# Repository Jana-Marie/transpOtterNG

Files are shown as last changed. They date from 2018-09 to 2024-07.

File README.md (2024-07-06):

# TranspOtterNG

Next Generation of TranspOtter.

[Firmware](https://github.com/NiklasFauth/hoverboard-firmware-hack/tree/transpotter)

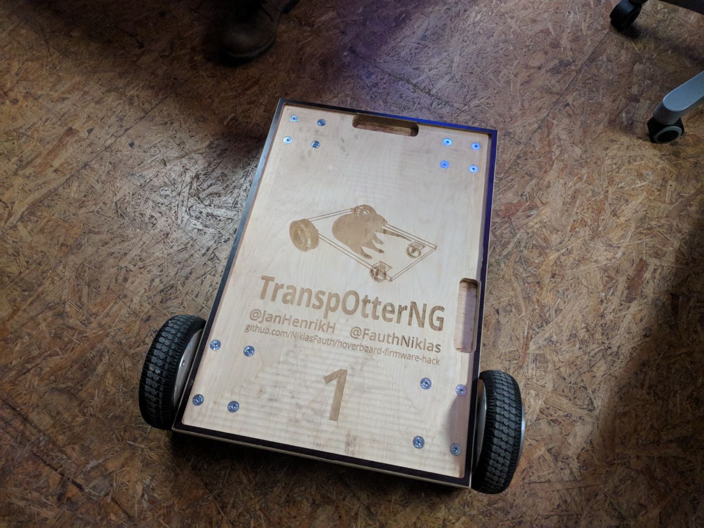
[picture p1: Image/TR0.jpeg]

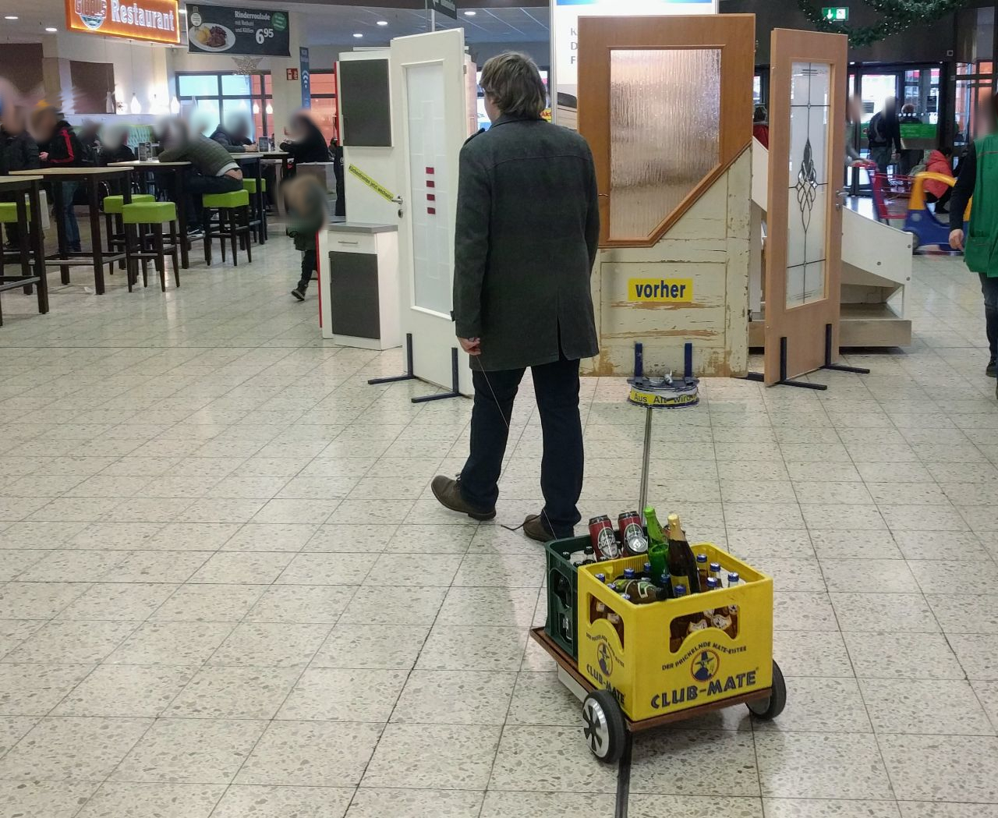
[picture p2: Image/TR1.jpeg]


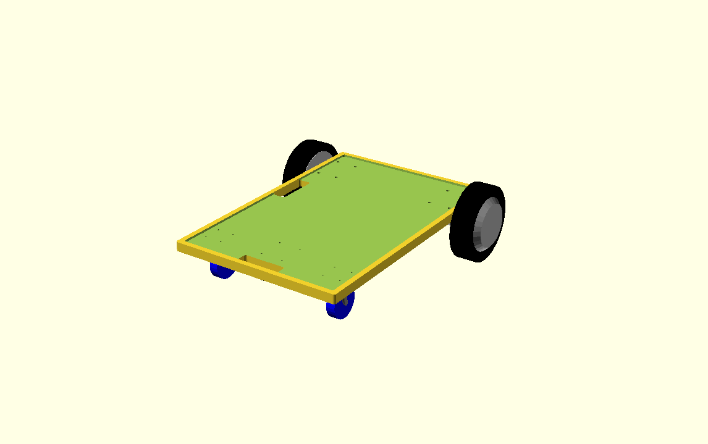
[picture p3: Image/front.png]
Front

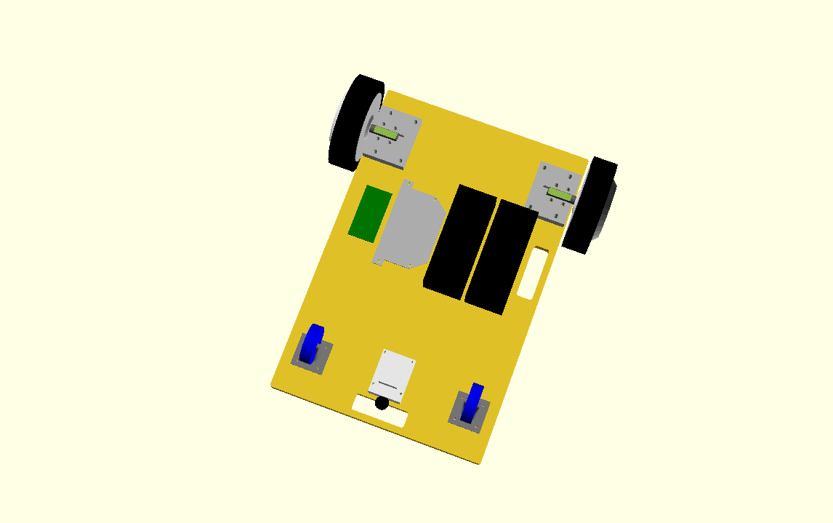
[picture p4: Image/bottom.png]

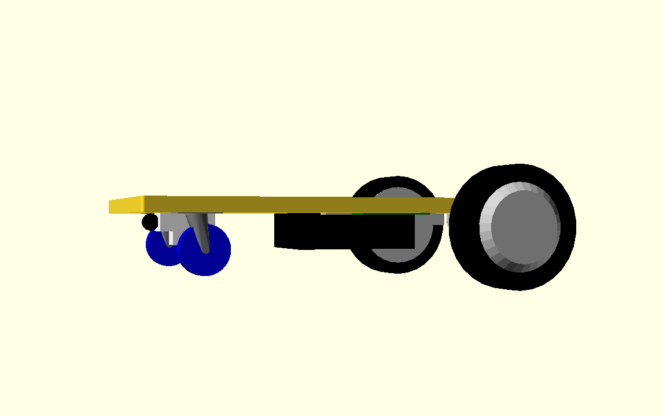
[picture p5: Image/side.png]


[Generation 1](https://github.com/NiklasFauth/hoverboard-firmware-hack/wiki/Build-Instruction:-TranspOtter)

## Libs

https://github.com/Jana-Marie/KiCAD-libs

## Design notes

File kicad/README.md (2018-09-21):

# Kicad project

This PCB will connect the mainboard to the Nunchuck, Gametrak and the Display.
Also it will provide 5V and 3.3V as well as the emergency stop.

## To do:

 - Add ESP and RFM69
 - Fit connectors
 - Check size
 - Add an Otter

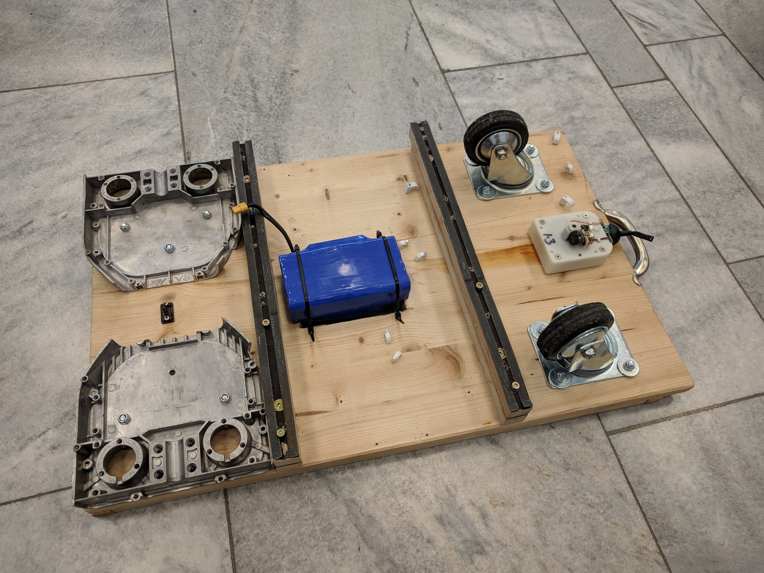
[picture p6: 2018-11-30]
Image/docs/board_bare_overview.jpg

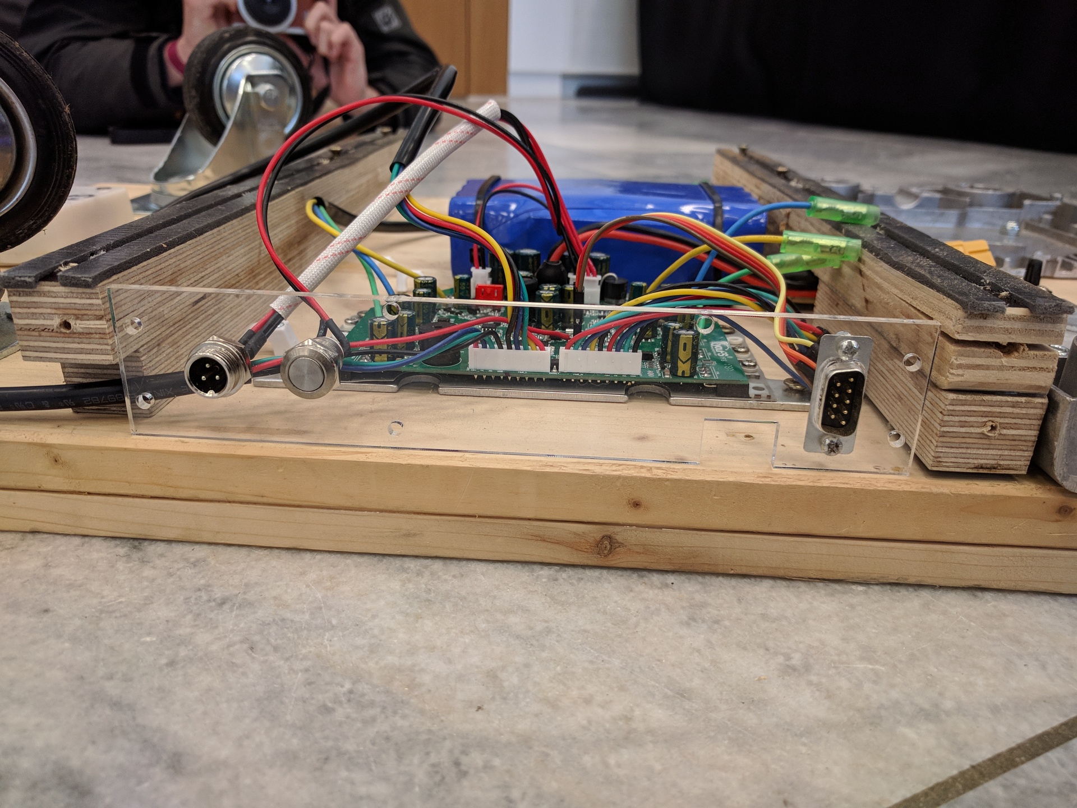
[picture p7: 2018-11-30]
Image/docs/panel_overview.jpg

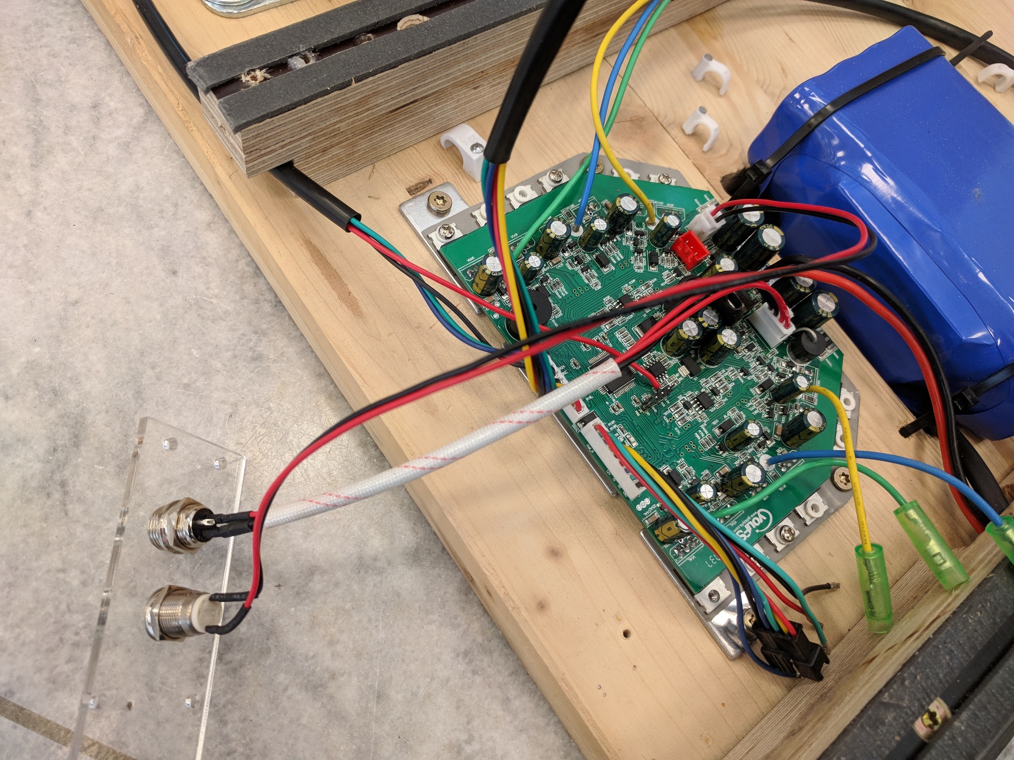
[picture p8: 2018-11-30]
Image/docs/charger_and_button.jpg

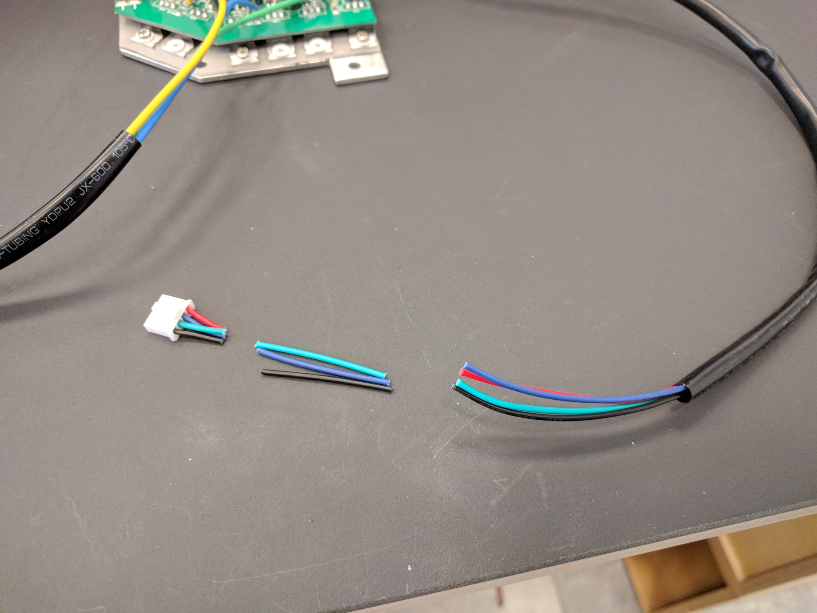
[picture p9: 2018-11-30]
Image/docs/remove_connector.jpg

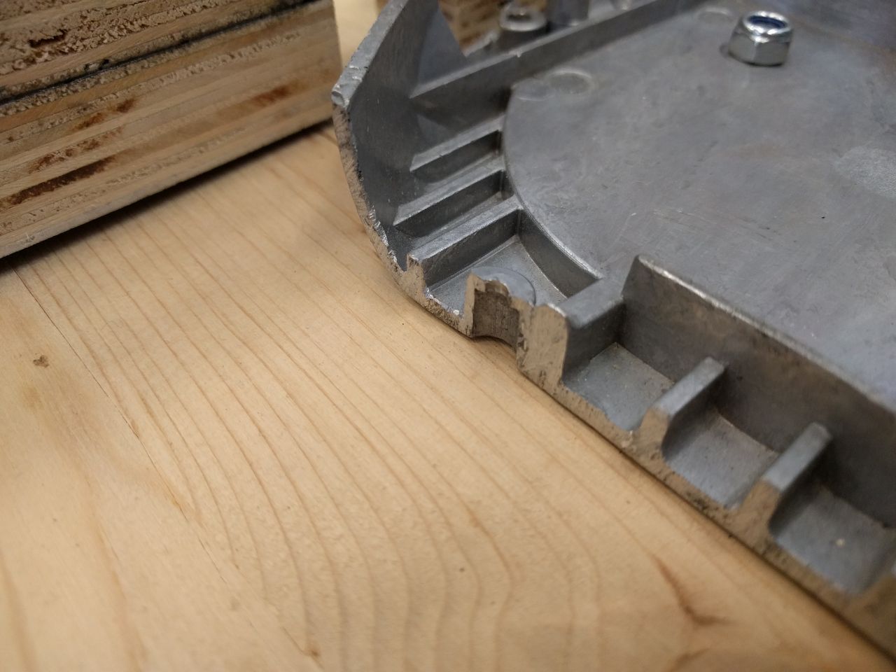
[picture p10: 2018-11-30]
Image/docs/motor_bracket_deburr.jpg

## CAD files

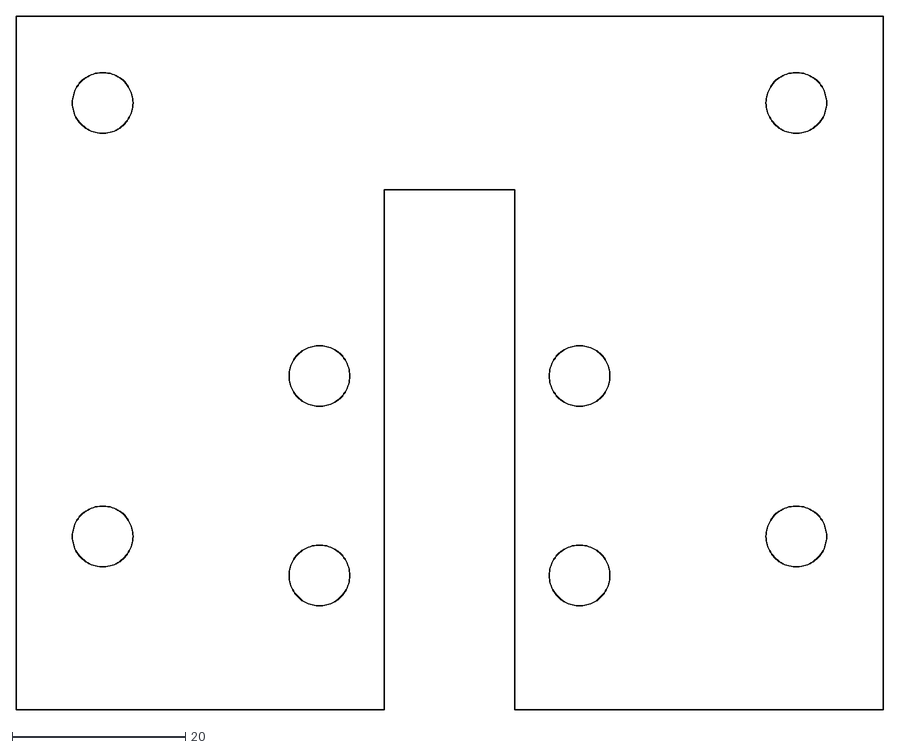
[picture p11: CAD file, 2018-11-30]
CAD/TranspOtterNG_Motor.dxf
100.0 x 80.0

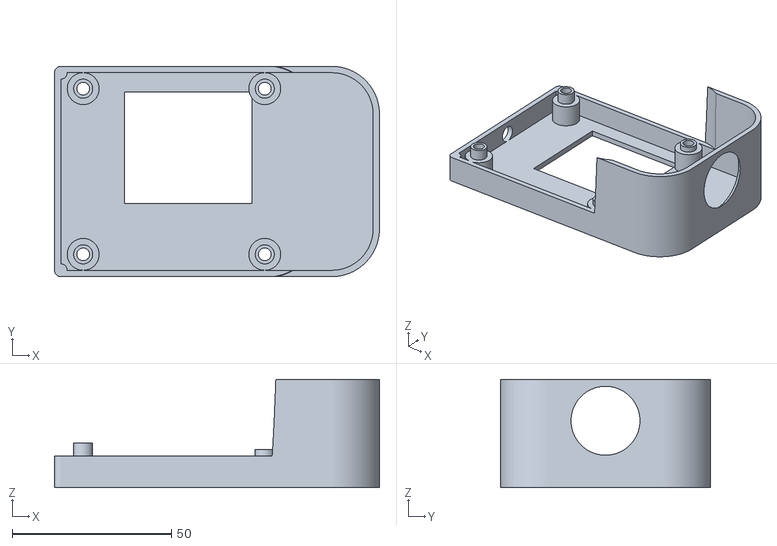
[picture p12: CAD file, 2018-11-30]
CAD/gametrak_base.stl
102.0 x 66.0 x 34.0

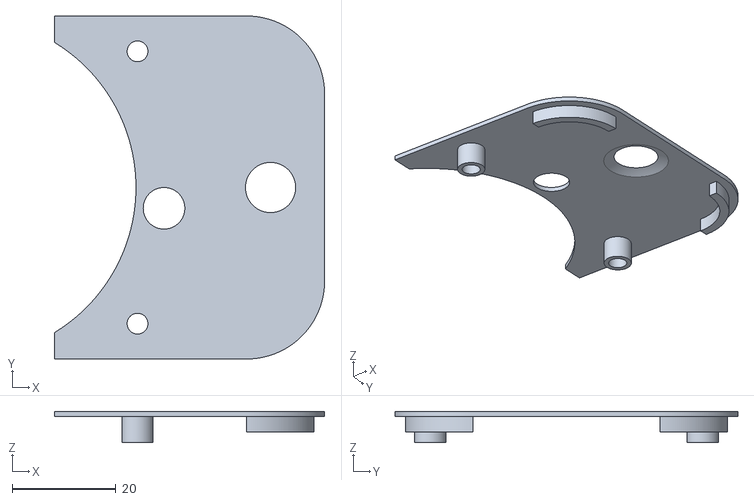
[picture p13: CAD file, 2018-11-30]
CAD/gametrak_top.stl
52.0 x 66.0 x 6.00

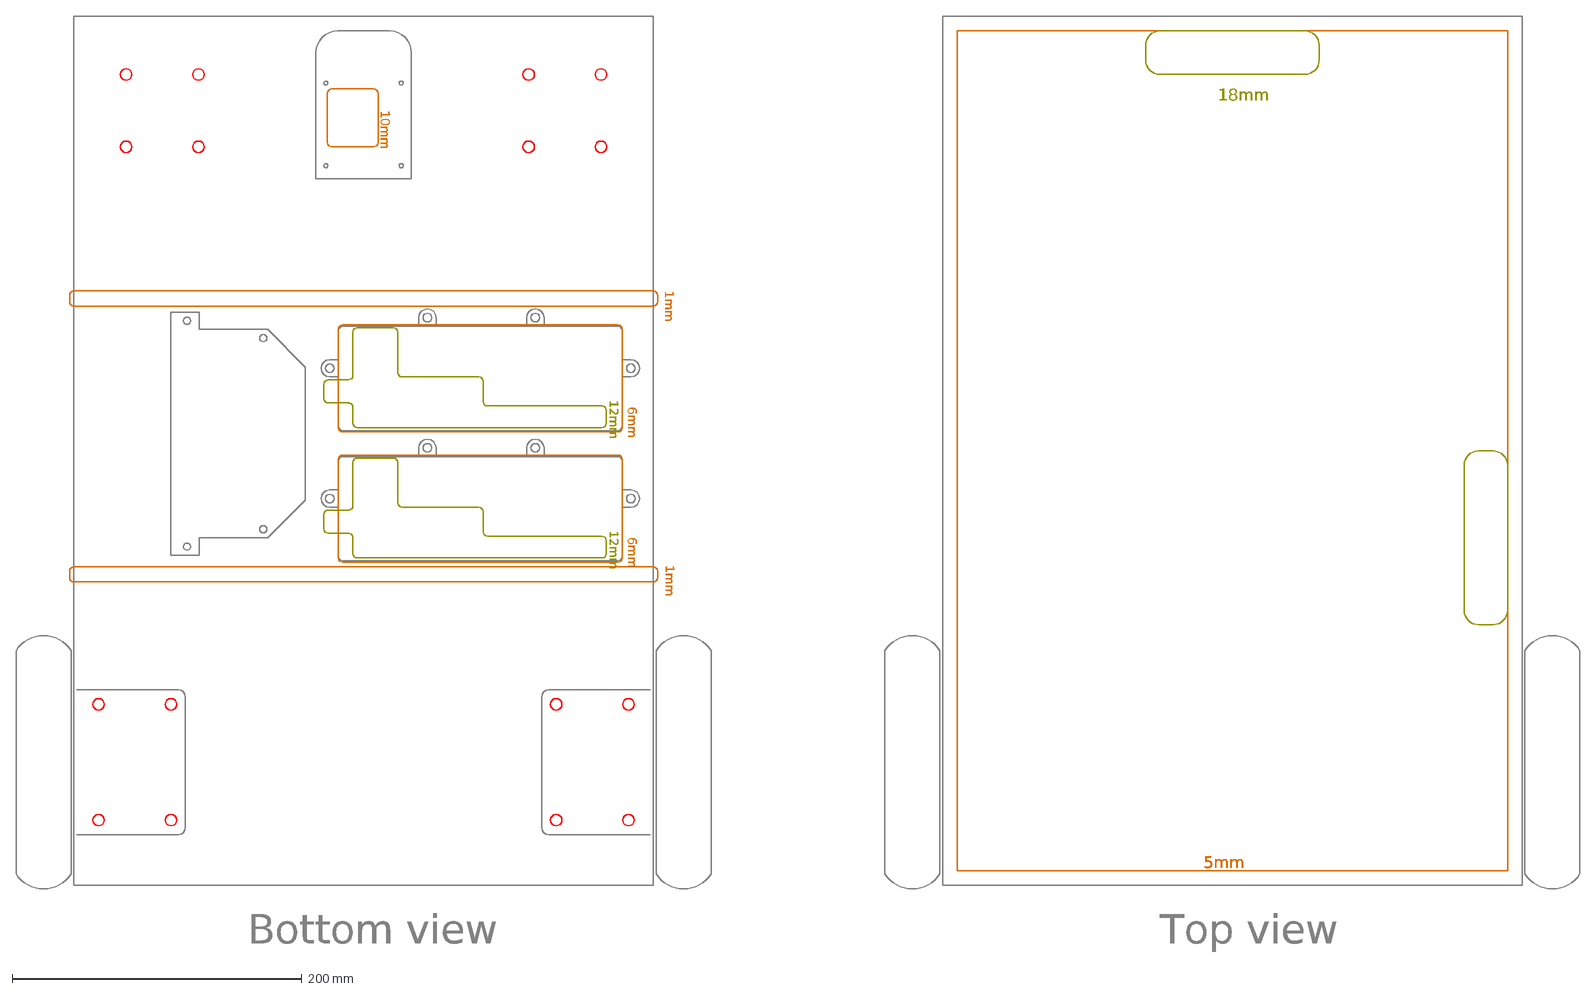
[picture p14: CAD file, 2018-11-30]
CAD/design.dxf
6mm
12mm
10mm
1mm
Bottom view
Top view
18mm
5mm

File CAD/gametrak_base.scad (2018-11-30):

$fn = 200;

difference() {
    translate([0,-31,0])cube([102-15,62,2]);
    translate([22,-10,-0.5])cube([40,35,3]);
    translate([9,-26,0])cylinder(r = 2, h = 20);
    translate([9,26,0])cylinder(r = 2, h = 20);
    translate([66,-26])cylinder(r = 2, h = 20);
    translate([66,26,0])cylinder(r = 2, h = 20);
}

translate([87,18,0])cylinder(r = 15, h = 2);
translate([87,-18,0])cylinder(r = 15, h = 2);
translate([87,-18,0])cube([15,35,2]);
    

translate([2,-31,0])cylinder(r = 2, h = 10);
translate([2,31,0])cylinder(r = 2, h = 10);

difference() {
    translate([0,-31,0])cube([2,62,10]);
    translate([0,0,5])rotate([0,90,0])cylinder(d=6, h = 5);
}

translate([2,-33,0])cube([85,2,10]);
translate([2,31,0])cube([85,2,10]);

difference() {
    union() {
        translate([9,-26,0])cylinder(r = 5, h = 10);
        translate([9,26,0])cylinder(r = 5, h = 10);
        translate([66,-26])cylinder(r = 5, h = 10);
        translate([66,26,0])cylinder(r = 5, h = 10);
        
        translate([9,-26,0])cylinder(r = 3, h = 14);
        translate([9,26,0])cylinder(r = 3, h = 14);
        translate([66,-26])cylinder(r = 3, h = 12);
        translate([66,26,0])cylinder(r = 3, h = 12);
    }
    translate([9,-26,0])cylinder(r = 2, h = 20);
    translate([9,26,0])cylinder(r = 2, h = 20);
    translate([66,-26])cylinder(r = 2, h = 20);
    translate([66,26,0])cylinder(r = 2, h = 20);
}

/*
intersection() {
    difference() {
        translate([67,18,0])cylinder(r = 15, h = 10);
        translate([67,18,0])cylinder(r = 13, h = 10);
    }
    translate([67,18,0])cube([15,15,10]);
}

intersection() {
    difference() {
        translate([67,-18,0])cylinder(r = 15, h = 10);
        translate([67,-18,0])cylinder(r = 13, h = 10);
    }
    translate([67,-18-15,0])cube([15,15,10]);
}
*/

intersection() {
    difference() {
        translate([87,18,0])cylinder(r = 15, h = 34);
        translate([87,18,0])cylinder(r = 13, h = 34);
    }
    translate([87,18,0])cube([15,15,34]);
}

intersection() {
    difference() {
        translate([87,-18,0])cylinder(r = 15, h = 34);
        translate([87,-18,0])cylinder(r = 13, h = 34);
    }
    translate([87,-18-15,0])cube([15,15,34]);
}

difference() {
    translate([67,31,0])cube([20,2,34]);
    translate([67,18,0])cylinder(r1 = 15, r2 = 15.2, h = 34);
}

difference() {
    translate([67,-33,0])cube([20,2,34]);
    translate([67,-18,0])cylinder(r1 = 15, r2 = 15.2, h = 34);
}

difference() {
    translate([100,-18,0])cube([2,36,34]);
    translate([91.6,0,21])rotate([0,90,0])sphere(d=30);
    //translate([99,0,21])rotate([0,90,0])resize([15,20])cylinder(d=20, h=5);
}

/*
difference() {
    union() {
        translate([87,18,33])cylinder(r = 15, h = 1);
        translate([87,-18,33])cylinder(r = 15, h = 1);
        translate([87,-18,33])cube([15,35,1]);
        translate([87-20,-18-15,33])cube([20,66,1]);
    }
translate([67,-18,31])cylinder(r1 = 15, r2 = 15.2, h = 10);
translate([67,18,31])cylinder(r1 = 15, r2 = 15.2, h = 12);
translate([67,-18,31])cube([15,35,3]);
}*/
//translate([81,-17.5,33])cube([15,35,1]);

    
    
    
    
    
    
    
    
    
    
    
    
    
    
    
    
    
    
    

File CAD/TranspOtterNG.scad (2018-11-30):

$fn=9;
//    batteryBosch3D();

motorplate2D_part2();

module frame2D(){
    height = 21;
    cutout_depht = 5;
    
    hoverbaord_motor_offset = -210;
    hoverbaord_motor_mount_spacing = -157;
    hoverbaord_motor_spacing = -147;
    
    wheel_offset = 220;
    wheel_spacing = 150;
    
    gametrak_offset = 210;
    
    mainboard_offset = -60;
    mainboard_offset_y = 110;
    mainboard_rotation = 270;
    
    pcb_offset = -60;
    pcb_offset_y = 10; 
    
    battery_offset_x = -60;
    battery_offset_y = -70;
    battery_rotation = 0;
    
    
    difference(){
        union(){
                base2D();

            
        }union(){
            translate([0,0,height-(cutout_depht/2)])
                cutout2D();
            
            
            translate([hoverbaord_motor_offset,hoverbaord_motor_mount_spacing,0])
                motorplate2D_cutout();
            
            
            mirror([0,1,0])
            translate([hoverbaord_motor_offset,hoverbaord_motor_mount_spacing,0])
                motorplate2D_cutout();
            
            
            translate([wheel_offset,wheel_spacing,0])
                wheel2D_cutout();
            
                        
            mirror([0,1,0])
            translate([wheel_offset,wheel_spacing,0])           
                wheel2D_cutout();
            
            
            translate([gametrak_offset,0,10])
                gametrak2D();
            
        }
    }
}

module frame3D(){
    height = 21;
    cutout_depht = 5;
    
    hoverbaord_motor_offset = -210;
    hoverbaord_motor_mount_spacing = -157;
    hoverbaord_motor_spacing = -147;
    
    wheel_offset = 220;
    wheel_spacing = 150;
    
    gametrak_offset = 210;
    
    mainboard_offset = -60;
    mainboard_offset_y = 120;
    mainboard_rotation = 270;
    
    pcb_offset = -60;
    pcb_offset_y = 10; 
    
    battery_offset_x = -50;
    battery_offset_y = -70;
    battery_rotation = 0;
    
    difference(){
        union(){
            translate([0,0,height/2])
            linear_extrude(height = height, center = true, convexity = 10,  slices = 20) {
                base2D();
            }
            
            translate([hoverbaord_motor_offset,hoverbaord_motor_mount_spacing,0])
            color("silver")
            motorplate3D();
                        
            mirror([0,1,0])
            translate([hoverbaord_motor_offset,hoverbaord_motor_mount_spacing,0])
            color("silver")
            motorplate3D();
            
            translate([hoverbaord_motor_offset,hoverbaord_motor_spacing,-20])
            motor3D();
                        
            mirror([0,1,0])
            translate([hoverbaord_motor_offset,hoverbaord_motor_spacing,-20])
            motor3D();
            
            translate([wheel_offset,wheel_spacing,0])
            wheel3D();
                        
            mirror([0,1,0])
            translate([wheel_offset,wheel_spacing,0])
            wheel3D();
            
            translate([gametrak_offset,0,0])
            gametrak3D();
            
            translate([mainboard_offset,mainboard_offset_y,-1])
            rotate([0,0,mainboard_rotation])
            mainboard3D();
            
            translate([pcb_offset,mainboard_offset_y+pcb_offset_y,-1])
            rotate([0,0,mainboard_rotation])
            pcb3D();

            
        }union(){
            translate([0,0,height-(cutout_depht/2)])
            linear_extrude(height = cutout_depht+0.01, center = true, convexity = 10,  slices = 20) {
                cutout2D();
            }
            
            translate([hoverbaord_motor_offset,hoverbaord_motor_mount_spacing,height/2])
            linear_extrude(height = height+0.01, center = true, convexity = 10,  slices = 20) {
                motorplate2D_cutout();
            }
            
            mirror([0,1,0])
            translate([hoverbaord_motor_offset,hoverbaord_motor_mount_spacing,height/2])
            linear_extrude(height = height+0.01, center = true, convexity = 10,  slices = 20) {
                motorplate2D_cutout();
            }
            
            translate([wheel_offset,wheel_spacing,10])
            linear_extrude(height = height+0.01, center = true, convexity = 10,  slices = 20) {
                wheel2D_cutout();
            }
                        
            mirror([0,1,0])
            translate([wheel_offset,wheel_spacing,10])           
            linear_extrude(height = height+0.01, center = true, convexity = 10,  slices = 20) {
                wheel2D_cutout();
            }
            
            translate([gametrak_offset,0,10])
            linear_extrude(height = height+0.01, center = true, convexity = 10,  slices = 20) {
                gametrak2D();
            }
        }
    }
    translate([battery_offset_x,battery_offset_y+(72/2)+5.5,-56/2])
    rotate([0,0,battery_rotation])
    batteryBosch3D();
    
    translate([battery_offset_x,battery_offset_y-(72/2)-5.5,-56/2])
    rotate([0,0,battery_rotation])
    batteryBosch3D();
}
module base2D(){
    length = 600;
    width = 400;
    rad = 5;
    //handle
    handle_length = 100;
    handle_width = 30;
    handle_offset = 24.5;
    handle_rad = 5;
    difference(){
        union(){
            minkowski(){
                square([length-(rad*2),width-(rad*2)],center=true);
                circle(r=rad);
            }
        }union(){
            //Handle 1
            translate([(length-handle_width-handle_offset)/2,0])
            minkowski(){
                square([handle_width-(handle_rad*2),handle_length-(handle_rad*2)],center=true);
                circle(r=handle_rad);
            }
            //Handle 2
            translate([-60,(-width+handle_width+handle_offset)/2])
            minkowski(){
                square([handle_length-(handle_rad*2),handle_width-(handle_rad*2)],center=true);
                circle(r=handle_rad);
            }
        }
    }
}

module cutout2D(){
    length = 575;
    width = 375;
    rad = 5;
    difference(){
        union(){
            minkowski(){
                square([length-(rad*2),width-(rad*2)],center=true);
                circle(r=rad);
            }
        }union(){
        }
    }
}

module gametrak2D(){
    mount_hole_size = 4.1;
    mount_hole_x = 60;
    mount_hole_y = 52;
    mount_hole_offset = -5;
    
    for(i = [-1:2:1]){
        for(j=[-1:2:1]){
            translate([i*(mount_hole_x/2)+mount_hole_offset,j*(mount_hole_y/2)])
            circle(d=mount_hole_size);
        }
    }
}

module gametrak3D(){
    translate([0,0,-(27/2)])
    difference(){
        union(){
            color("white")
            cube([80,60,27],center=true);
            translate([0,0,-(27/2)-(20/2)])
            color("white")
            cube([40,35,20],center=true);
            color("black")
            translate([50,0,0])
            sphere(d=25);
            
        }union(){
            linear_extrude(height = 27, center = true, convexity = 10,  slices = 20) {
                gametrak2D();
            }
        }
    }
}

module motorplate3D(){
    height = 10;
    height2 = 10;
    translate([0,0,-height/2])
    linear_extrude(height = height, center = true, convexity = 10,  slices = 20) {
        motorplate2D();
    }
    translate([0,0,-height-height2/2])
    linear_extrude(height = height2, center = true, convexity = 10,  slices = 20) {
        motorplate2D_part2();
    }
}

module motorplate2D_cutout(){
    mount_hole_size = 7;
    mount_hole_x = 80;
    mount_hole_y = 50;
    mount_hole_offset = 5;
    
    for(i = [-1:2:1]){
        for(j=[-1:2:1]){
            translate([i*(mount_hole_x/2),j*(mount_hole_y/2)+mount_hole_offset])circle(d=mount_hole_size);
        }
    }
}

module motorplate2D(){
    length = 80;
    width = 100;
    board_hole_size = 7;
    board_hole_x = 30;
    board_hole_y = 23;
    board_hole_offset = -13;
    difference(){
        union(){
            square([width,length],center=true);
        }union(){
           motorplate2D_cutout();
            for(i = [-1:2:1]){
                for(j=[-1:2:1]){
                    translate([i*(board_hole_x/2),j*(board_hole_y/2)+board_hole_offset])
                    circle(d=board_hole_size);
                }
            }
        }
    }
}

module motorplate2D_part2(){
    length = 80;
    width = 100;
    shaft_width = 15;
    shaft_length = 60;
    
    difference(){
        union(){
            motorplate2D();
        }union(){
            motorplate2D_cutout();
            translate([0,-(length/2)+(shaft_length/2)])
            square([shaft_width,shaft_length],center=true);
        }
    }
}
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

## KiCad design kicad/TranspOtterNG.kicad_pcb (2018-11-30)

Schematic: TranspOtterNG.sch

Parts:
AE1: Antenna; Pin_D1.0mm_L10.0mm
C1, C2, C3, C10, C13: 100n; C_0603_1608Metric
C4: 1u; C_0805_2012Metric
C5, C6, C7, C8: 10n; C_0603_1608Metric
C9, C12: 20u; CP_Elec_5x5.3
C14: C_Small; C_0603_1608Metric
D1: 12V; D_SOD-323
D3: LED; LED_0805_2012Metric
J1: UART/I2C; JST_XH_B04B-XH-A_1x04_P2.50mm_Vertical
J2: UART/IO/ANALOG; JST_XH_B04B-XH-A_1x04_P2.50mm_Vertical
J3: Conn_01x04_Male; PinHeader_1x04_P2.54mm_Vertical
J4: GameTrak; PinHeader_1x04_P2.54mm_Vertical
J7: xt30; XT60_angle
J8: Conn_01x05_Male; PinHeader_1x05_P2.54mm_Vertical
J9: Conn_01x16_Female; PinHeader_1x16_P2.54mm_Vertical
MH1, MH2, MH3, MH4: MountingHole; MountingHole_3.2mm_M3
P1: CONN_WII
Q1: Q_NMOS_GDS; SOT-23
Q2: Q_PMOS_GDS; TO-252-2
R1: 470; R_0603_1608Metric
R2, R3: 3k3; R_0603_1608Metric
R4, R5, R6, R7: 1k; R_0603_1608Metric
R8, R9, R21, R22, R23: DNP; R_0603_1608Metric
R10, R11, R12, R13, R14, R18, R19, R20, R27, R28: 10k; R_0603_1608Metric
R15, R16, R17: 100k; R_0603_1608Metric
R26: 220; R_0603_1608Metric
SW1: Flash; SW_DIP_SPSTx01_Slide_Copal_CHS-01A_W5.08mm_P1.27mm_JPin
SW2: Reset; SW_DIP_SPSTx01_Slide_Copal_CHS-01A_W5.08mm_P1.27mm_JPin
U1: AMS1117; SOT-223-3_TabPin2
U2: URB4805YMD-6WR3
U3: RFM69HCW; HOPERF_RFM69HW
U4: ESP-12E
U5: PCF8574; SOIC-16W_7.5x10.3mm_P1.27mm

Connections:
+5V: C2.1, C10.1, C12.1, J3.4, J9.2, J9.15, R18.1, R19.1, R20.1, R27.2, U1.3 (VI), U2.3, U5.16
+15V: J1.1, R15.1
A0: R18.2, R21.2, U5.1
A1: R19.2, R22.2, U5.2
A2: R20.2, R23.2, U5.3
ANT: C14.2, U3.9 (ANT)
CS: J9.6, U5.6
DB4: J9.11, U5.9
DB5: J9.12, U5.10
DB6: J9.13, U5.11
DB7: J9.14, U5.12
GND: C1.2, C2.2, C3.2, C4.2, C5.2, C6.2, C7.2, C8.2, C9.2, C10.2, C12.2, C13.2, J1.4, J2.4, J3.1, J4.1, J7.1, J8.4, J9.1, P1.6, Q1.2, R1.2, R8.2, R9.2, R10.2, R16.2, R21.1, R22.1, R23.1, R26.1, R28.1, SW1.1, SW2.1, U1.1 (ADJ), U2.1, U2.5, U3.1 (GND), U3.8 (GND), U3.10 (GND), U4.15, U5.8
GPIO0: R14.2, SW1.2, U4.18
GPIO4: U3.14 (DIO0), U4.19
GPIO5: J8.3, U4.20
LED_K: J9.16, R26.2
MISO: U3.2 (MISO), U4.6
MOSI: U3.3 (MOSI), U4.7
NSS: R10.1, U3.5 (NSS), U4.16
unnamed: AE1.1, C14.1
unnamed: C5.1, J1.2, R4.2
unnamed: C6.1, J2.2, R6.2
unnamed: C7.1, J1.3, R5.2
unnamed: C8.1, J2.3, R7.2
unnamed: C9.1, Q2.2, U2.2
unnamed: C13.1, R12.1, U4.3
unnamed: D1.1, J7.2, Q2.3
unnamed: D1.2, Q2.1, R17.1
unnamed: D3.1, R1.1
unnamed: Q1.1, R15.2, R16.1
unnamed: Q1.3, R17.2
P3: U5.7
RESET: C1.1, R11.2, SW2.2, U4.1
RS: J9.4, U5.4
RW: J9.5, U5.5
RX0_SDA: P1.5, R3.2, R5.1, U5.15
RX1_ADC2: J4.3, R7.1, R8.1
RXD_ESP: J8.2, U4.21
SCK: U3.4 (SCK), U4.5
TX0_SCL: P1.2, R2.2, R4.1, U5.14
TX1_ADC1: J4.2, R6.1, R9.1
TXD_ESP: J8.1, U4.22
VCC: C3.1, C4.1, D3.2, J3.3, J4.4, J8.5, P1.1, R2.1, R3.1, R11.1, R12.2, R13.1, R14.1, U1.2 (VO), U3.13 (3.3V), U4.8
VO: J9.3, R27.1, R28.2
WS2812: J3.2, R13.2, U4.17

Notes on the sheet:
Input
LDO
LED
I2C
ADC
Nunchuk
VCC

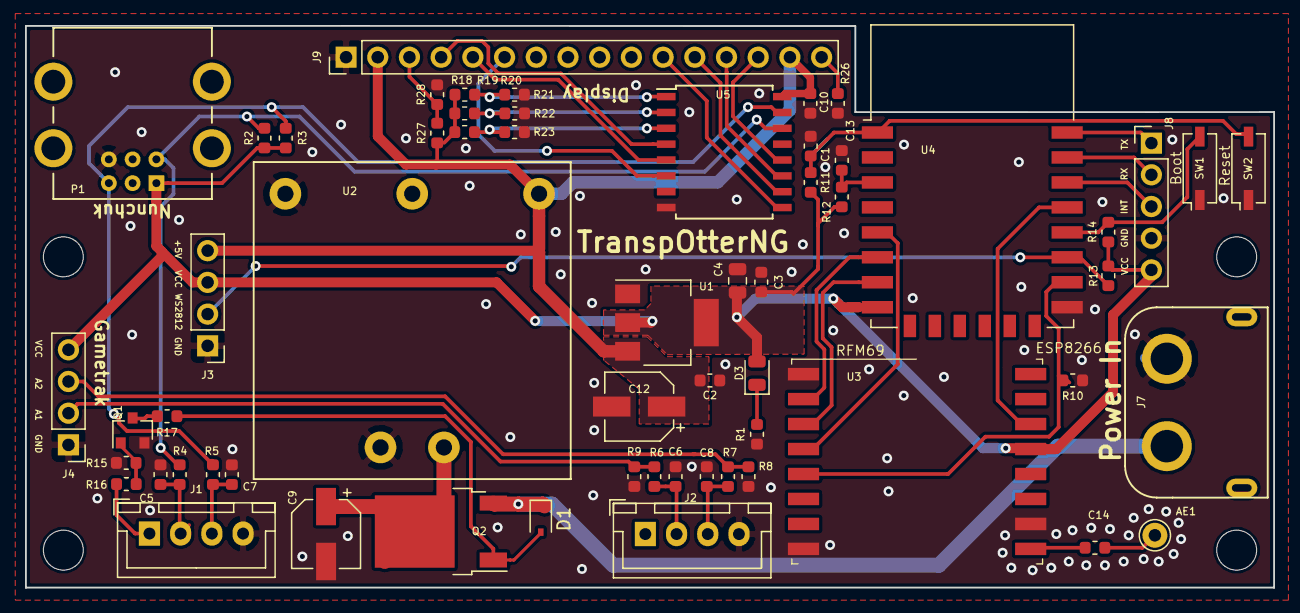
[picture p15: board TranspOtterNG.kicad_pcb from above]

Board: 2 copper layers, 100.0 x 45.0 mm, 63 parts (0 on the bottom side), 44 nets.

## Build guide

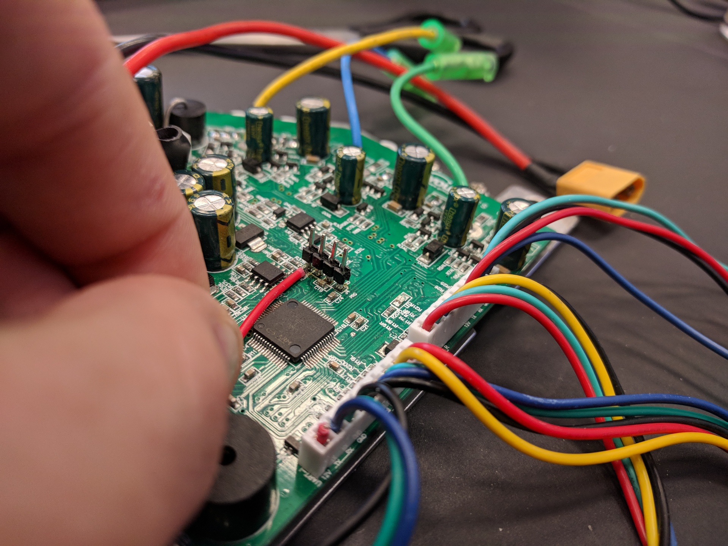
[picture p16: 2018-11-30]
Image/docs/howto_solder_3V3.jpg

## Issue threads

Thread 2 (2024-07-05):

Gametrak CAD models wrong/missing

Pixtxa, 2024-07-05:
The base fits perfect:
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
But there is a part left open, for that I cant't find a 3D Model to print it. Is it something to buy? Or is just the model missing?

The top part doesn't really fit in the Mounting holes and bends.
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
I've compared the 3D models and the mounting holes on the top part are a bit too wide.
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
Thought it should be a little thing to change, but the OpenSCAD-File is also missing.

Also would be nice to have some pictures of the bottom side of the real TranspotterNG. The twitter links to videos are broken.

Jana-Marie, 2024-07-06:
Hey @Pixtxa, I'm sorry that it doesn't fit well for you. The hole is left intentionally blank, I mounted most of my gametraks with the mechanism facing the wood (I have milled a pocket into my wooden bases. You probably want to add some kind of protection when the mechanism is facing down.

As for the holes, I think that you are right and they should be. I don't have a gametrak left over, could you measure the upper and lower hole distances? I will be able to change the cad file for you

Pixtxa, 2024-07-06:
Okay, I have 8 mm dibond, so making pockets doesn't really work. But I've designed a cover part now.
Gametrek is weird, the holes aren't straight. Made a top part with the holes on same distance than base part and it also dosn't fit. Maybe it worked for you, because you have an other hardware revision of the game trek? In some pictures they were white instead of clear.
If I screw it on tight, it doesn't work as good as it does unmounted. I've now changed the diameter of the border, because I want to use straight holes to screw it on and added a whole top lid, so I don't have to use washers like the first version of transpotter. I'll release my files when project is finished/they're printed and successfully tested.

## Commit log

2018-09-19 inital commit
    [TranspOtterNG.scad]
2018-09-20 changed battery type to F016 L67 804
    [TranspOtterNG.scad]
2018-09-20 added kicad project
    [TranspOtterNG.kicad_pcb, TranspOtterNG.sch]
2018-09-20 added kicad/README
2018-09-20 added stepdown
    [TranspOtterNG.kicad_pcb, TranspOtterNG.sch]
2018-09-20 changed parameters
    [TranspOtterNG.scad]
2018-09-21 added esp and rfm
    [TranspOtterNG.kicad_pcb, TranspOtterNG.sch]
2018-09-24 added programming header
    [TranspOtterNG.kicad_pcb, TranspOtterNG.sch]
2018-09-26 moved libraries
    [TranspOtterNG.kicad_pcb, TranspOtterNG.sch]
2018-10-13 v1 finished
    [TranspOtterNG.kicad_pcb, TranspOtterNG.sch]
2018-10-13 minor changes, now v2
    [TranspOtterNG.kicad_pcb, TranspOtterNG.sch]
2018-10-14 minor changes
    [TranspOtterNG-B.Cu.gbr, TranspOtterNG-B.Mask.gbr, TranspOtterNG-B.Paste.gbr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]
2018-10-15 update battery
    [TranspOtterNG.scad]
2018-11-08 update scad
    [TranspOtterNG.scad]
2018-11-30 ADD files for transpOtterNG-deluxe
    [design.dxf, gametrak_base.scad, gametrak_base.stl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]
